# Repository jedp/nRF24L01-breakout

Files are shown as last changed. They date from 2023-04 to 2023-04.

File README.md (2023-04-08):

# nRF24L01+ breakout board

The Nordic Semiconductor nRF24L01.

Antenna constructed according to AN043.

PCB View

## BOM

- C1: 22pF 0402
- C2: 22pF 0402
- C3: 2.2nF 0402
- C7: 33nF 0402
- C8: 1nF 0402
- C9: 10nF 0402
- C10: 4.7µF 0603
- J1: Conn 01x04 Female 2.54mm
- J2: Conn 01x04 Female 2.54mm
- R1: 1M 0402
- R2: 22k 0402
- R3: 0k 0603
- U1: NRF24L01 QFN-20
- U2: Antenna PCB 2.4GHz 50Ohm
- U3: Balun 2450BM14A0002 Johanson 1.6x0.8mm
- Y1: Crystal GND24 Small SMD_2520-4Pin 2.5x2.0mm

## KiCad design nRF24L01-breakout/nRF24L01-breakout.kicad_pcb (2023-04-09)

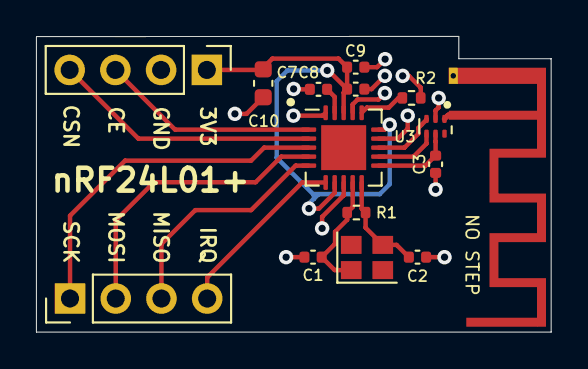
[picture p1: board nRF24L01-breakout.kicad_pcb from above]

Board: 2 copper layers, 28.6 x 16.4 mm, 16 parts (1 on the bottom side), 17 nets.

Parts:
C1, C2: 22pF; C_0402_1005Metric
C3: 2.2nF; C_0402_1005Metric
C7: 33nF; C_0402_1005Metric
C8: 1nF; C_0402_1005Metric
C9: 10nF; C_0402_1005Metric
C10: 4.7µF; C_0603_1608Metric
J1, J2: Conn_01x04_Female; PinHeader_1x04_P2.54mm_Vertical
R1: 1M; R_0402_1005Metric
R2: 22k; R_0402_1005Metric
R3: 0k; R_0603_1608Metric
U1: NRF24L01; QFN-20-1EP_4x4mm_P0.5mm_EP2.5x2.5mm
U2: Antenna_PCB_2.4GHz_50Ohm
U3: Balun_2450BM14A0002; Balun_Johanson_1.6x0.8mm
Y1: Crystal_GND24_Small; Crystal_SMD_2520-4Pin_2.5x2.0mm

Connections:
ANT1: U1.12 (ANT1), U3.4 (Bal2)
ANT2: U1.13 (ANT2), U3.3 (Bal1)
CE: J1.3, U1.1 (CE)
CSN: J1.4, U1.2 (CSN)
GND: C1.2, C2.2, C3.2, C7.2, C8.2, C9.2, C10.2, J1.2, R2.2, R3.2, U1.8 (VSS), U1.14 (VSS), U1.17 (VSS), U1.20 (VSS), U3.2 (GND)
IRQ: J2.4, U1.6 (IRQ)
MISO: J2.3, U1.5 (MISO)
MOSI: J2.2, U1.4 (MOSI)
unnamed: C7.1, U1.19 (DVDD)
unnamed: R2.1, U1.16 (IREF)
unnamed: R3.1, U2.2 (GND)
unnamed: U2.1 (ANT), U3.1 (Unbal)
SCK: J2.1, U1.3 (SCK)
VDD: C8.1, C9.1, C10.1, J1.1, U1.7 (VDD), U1.15 (VDD), U1.18 (VDD)
VDD_PA: C3.1, U1.11 (VDD_PA), U3.5 (DC)
XC1: C2.1, R1.1, U1.10 (XC1), Y1.3
XC2: C1.1, R1.2, U1.9 (XC2), Y1.1

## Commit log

2023-03-06 KiCad schematic and layout; Custom footprint for AN043 antenna.
    [nRF24L01-breakout.kicad_pcb, nRF24L01-breakout.kicad_sch]
2023-04-08 Use Johanson 2450BM14A0002 matched balun
    [nRF24L01-breakout.kicad_pcb, nRF24L01-breakout.kicad_sch]
2023-04-08 Fix balun footprint; Make board smaller
    [nRF24L01-breakout.kicad_pcb]
2023-04-08 Move a via away from a trace
    [nRF24L01-breakout.kicad_pcb]
2023-04-08 Added bom to readme
2023-04-09 Spread out signal traces
    [nRF24L01-breakout.kicad_pcb]
